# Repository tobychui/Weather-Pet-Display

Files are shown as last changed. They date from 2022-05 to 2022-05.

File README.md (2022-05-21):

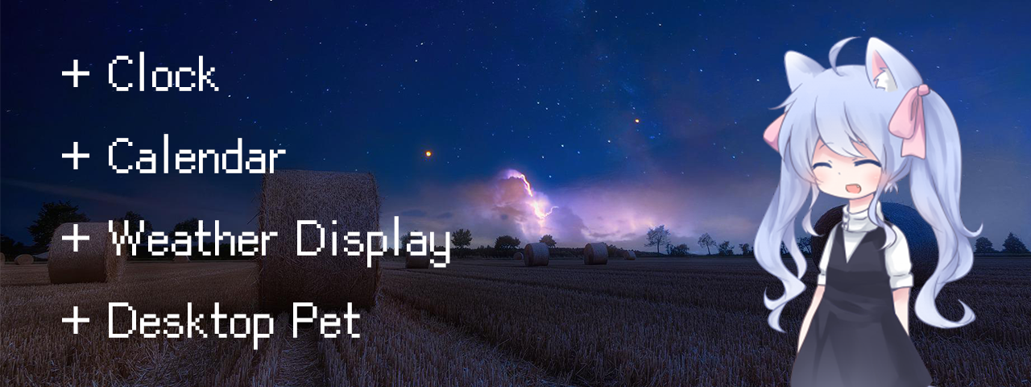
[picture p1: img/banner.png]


# Weather + Desktop Pet Display

A simple weather display with a cute interactive desktop pet  (❛◡❛✿)

## Introduction

Weather display is like one of the most done Maker project out there, involving simple parts and quite useful when put on your working desk. As a maker who is always trying to make beautiful yet technical projects, I decided to give it a try and challenge one of the most done project!

**Notes: This application provided only Tainan Weather by default (as this is where I currently live). If you need other location, please modify the code accordingly.**

## Build Instruction

### Material List

- ESP8266 (Wemos D1 Mini)
- UART HMI Display (The one used here is 5 inch touch screen model, TJC8048X550_011)
- Wires
- M3 x 10 screws x 2
- 3D printed base

### Building Instruction

1. Flash the program into the ESP8266 (See src/esp8266 folder)
2. Flash the program into the display using USART HMI Studio

3. Solder the following wires to the display 4 pin serial input

| Wemos D1 mini | UART HMI | Wire Color |
| --- | --- | --- |
| 5V | 5V | RED |
| GND | GND | BLACK |
| D1 | RX | BLUE |
| D2 | TX | YELLOW |

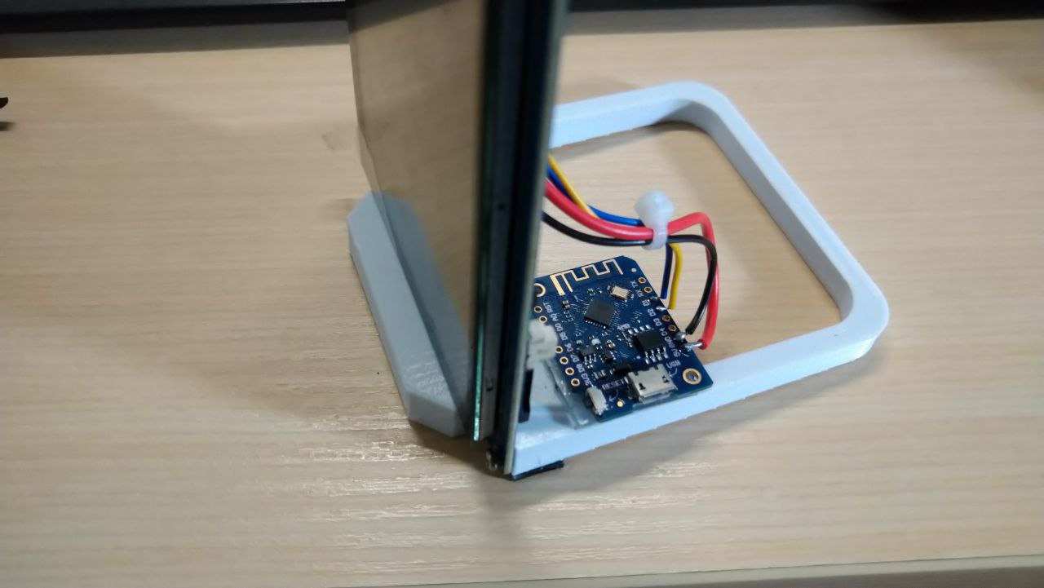
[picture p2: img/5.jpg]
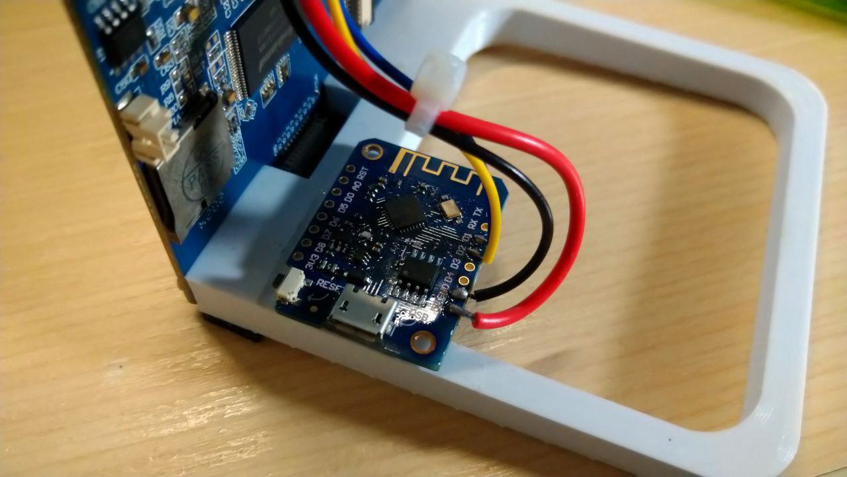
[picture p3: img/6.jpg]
|  |  |
| --- | --- |

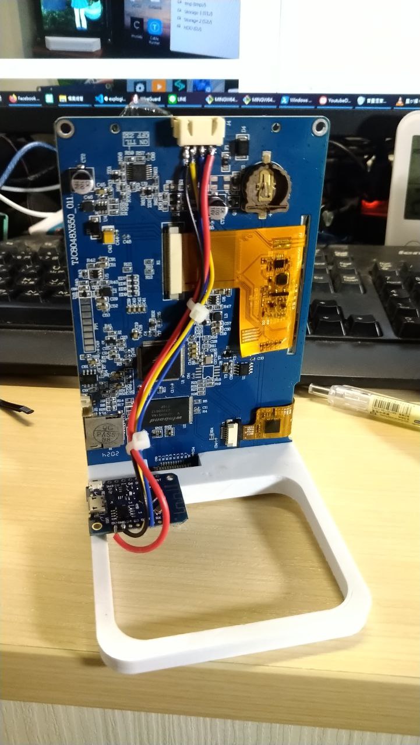
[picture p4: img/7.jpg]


4. Power it on, then it is done!

### WiFi Setup
This project uses [WiFi Manager](https://github.com/tzapu/WiFiManager). In which when ESP8266 first bootup, it will starts its own WiFi AP. You can simply connect to the WiFi AP using your phone and configure the ESP8266 to connect to your home network. Once you are done, the ESP8266 will wait for 1 secound and start grabbing weather information and date time information from the ineternet throught your home WiFi network.

## Photos

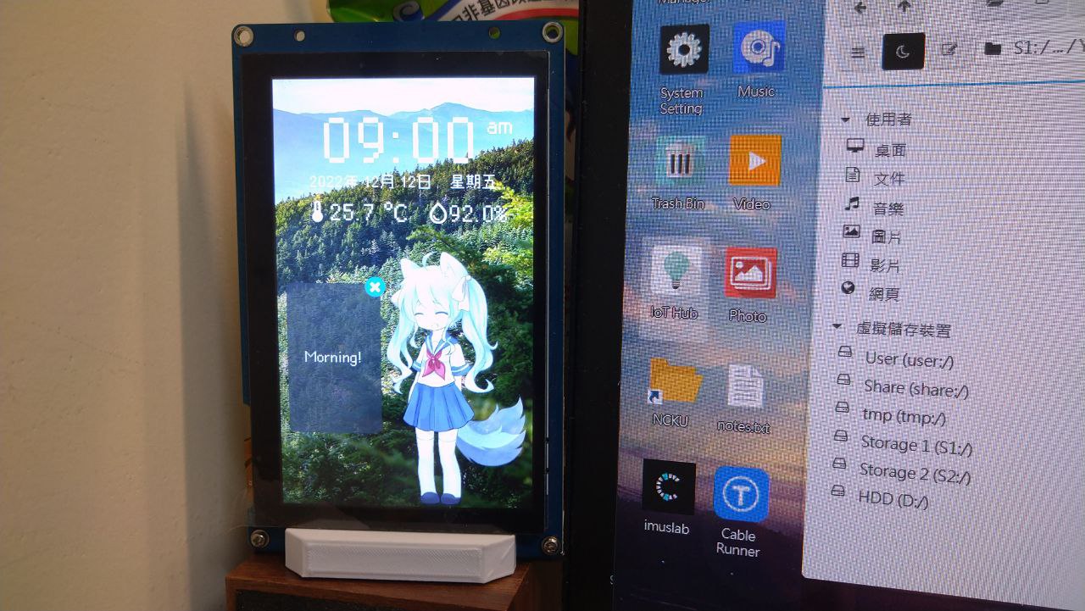
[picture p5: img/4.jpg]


Morning mode (Full brightness and in school uniform)

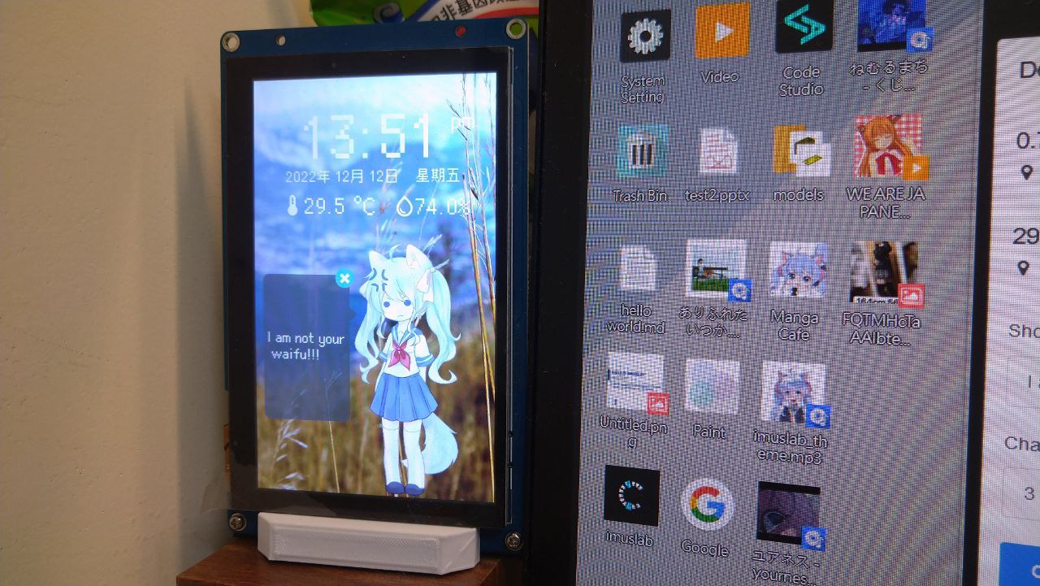
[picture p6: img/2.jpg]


Afternoon mode (Notice you can send in message and change facial expression via HTTP request)

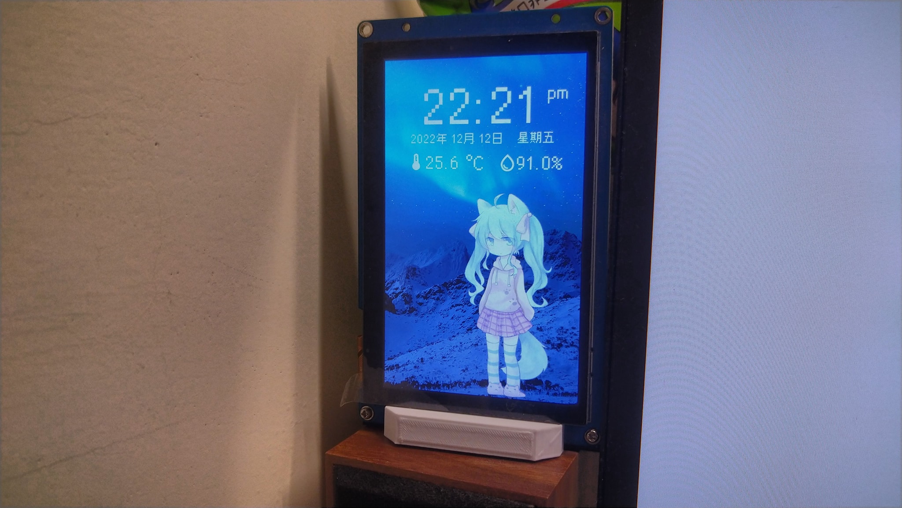
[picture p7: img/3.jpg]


Night mode, a bit more relaxing background and reduced brightness

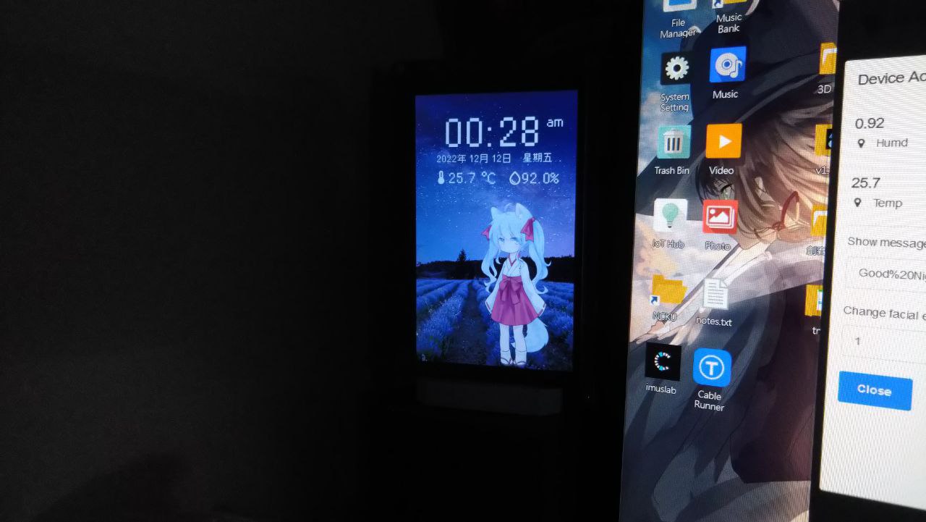
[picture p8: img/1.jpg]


Mid-night mode, set to lowest backlit LED brightness

## License

MIT

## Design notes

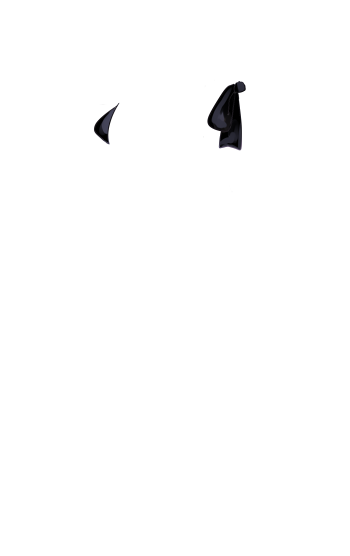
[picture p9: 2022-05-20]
src/res/ghost/surface1001.png

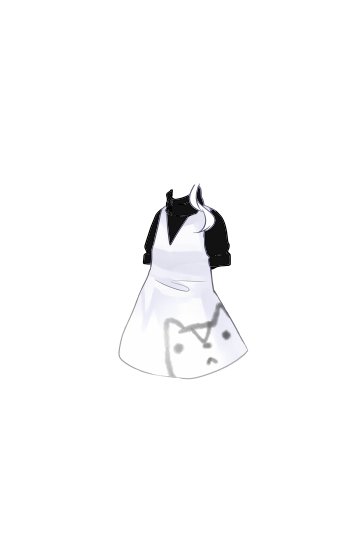
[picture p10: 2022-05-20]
src/res/ghost/surface1200.png

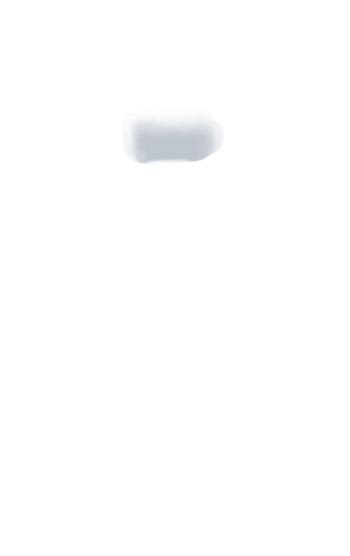
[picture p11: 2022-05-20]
src/res/ghost/surface55.png

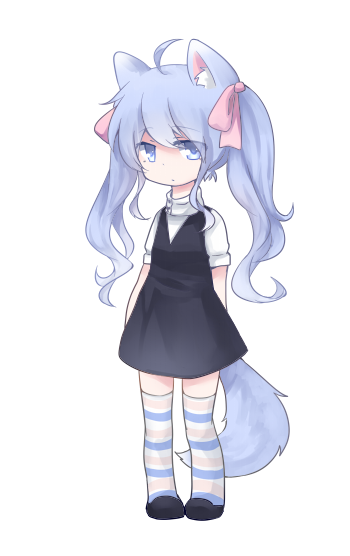
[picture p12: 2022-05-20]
src/res/ghost/surface8.png

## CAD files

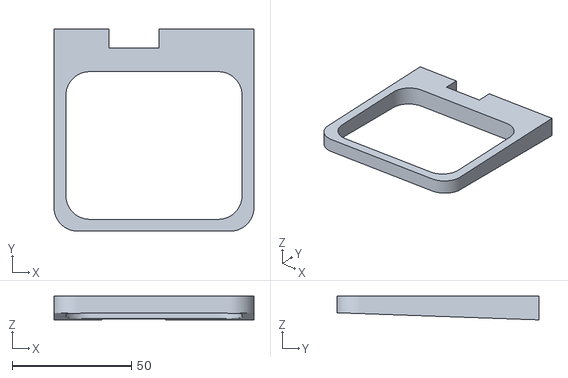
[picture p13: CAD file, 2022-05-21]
3d models/mount.stl
84.0 x 85.0 x 10.0

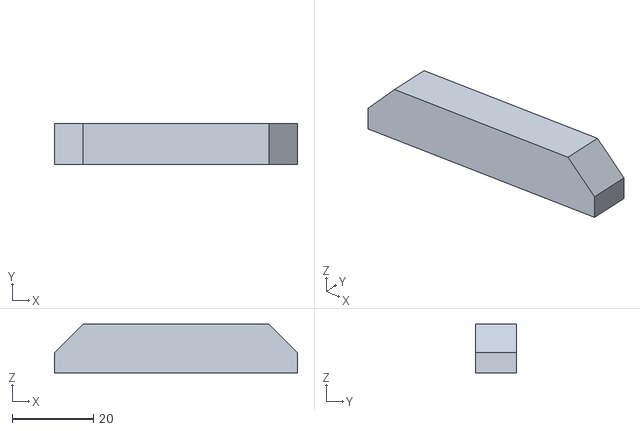
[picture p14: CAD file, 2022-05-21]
3d models/tip-over stopper.stl
60.0 x 10.0 x 12.0

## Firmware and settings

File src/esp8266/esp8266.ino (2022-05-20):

#include <ESP8266WiFi.h>
#include <NTPClient.h>
#include <WiFiUdp.h>
#include <SoftwareSerial.h>
#include <WiFiManager.h>
#include <ArduinoJson.h>

//Library required for HDSv2
#include <ESP8266mDNS.h>        // Include the mDNS library
#include <ESP8266WebServer.h>   // Include the WebServer library

//HMI Related
SoftwareSerial HMISerial(D1, D2); // RX, TX
bool debugMode = false;         //Enable debug mode

/*
 * HMI Element Definations 
 * 
 * time -> Time Display (00:00)
 * ampm -> am / pm text
 * date -> Current date, YYYY/MM/DD format 
 * dow -> Date of week, Monday to Sunday
 * 
 */
 
//WiFi Related
WiFiManager wifiManager;

//Properties of HDSv2 Devices
const String DeviceName = "ArOZ DSSP";     //The name of this IoT device
const int ListeningPort = 12110;           //The port where this IoT device listen
ESP8266WebServer server(ListeningPort);    //Create an Web Server on the listening port

//Clock Related
WiFiUDP UDPconn;
NTPClient ntpClient(UDPconn, "pool.ntp.org");
String weekDays[7]={"Sunday", "Monday", "Tuesday", "Wednesday", "Thursday", "Friday", "Saturday"};
String months[12]={"January", "February", "March", "April", "May", "June", "July", "August", "September", "October", "November", "December"};

//Weather related
//We are getting weather info from https://opendata.cwb.gov.tw/api/v1/rest/datastore/O-A0001-001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,HUMD&stationId=C0X100
const char* host = "opendata.cwb.gov.tw";
const char* stationId = "C0X100";
long cyclyCounter = 0;
DynamicJsonDocument doc(2048);
StaticJsonDocument<1024> filter;
String currentTemp = "N/A";
String currentHumd = "N/A";

//Background, messageBox & Clothing
/*
 *  Picture ID / Time
 *  30 (Early Morning): 5  - 8am
 *  31 (Morning)      : 9  - 12am
 *  32 (Afternoon)    : 13 - 15pm
 *  33 (Evening)      : 16 - 18pm
 *  34 (Night)        : 19 - 23pm
 *  35 (Late Night)   : 24 - 4am
 */

String currentBackgroundId = "0";


void setup() {
  // Start debug Serial and HMI Serial
  Serial.begin(115200);
  HMISerial.begin(9600);

  // Connect to Wi-Fi
  wifiManager.setClass("invert");
  wifiManager.autoConnect("ArOZ DSSP", "arozdssp");
  if (!debugMode){
    wifiManager.setDebugOutput(false);
  }

  //Start MDNS broadcast
  MDNS.setHostProbeResultCallback(hostProbeResult);
  if (!MDNS.begin(DeviceName) && debugMode) {
    Serial.println("Error setting up MDNS responder!");
  }

  //Advertise the port that you are using
  MDNS.addService("http", "tcp", ListeningPort);
  if (debugMode){
    Serial.println("mDNS responder started");
  }
  
  //Start WebServer
  delay(100);
  server.on("/", handle_index);
  server.on("/status", handle_status);
  server.on("/eps", handle_endpoints);
  server.on("/msg", handle_msg);
  server.on("/face", handle_face);
  
  server.begin();
  
  //Start NTP Client
  ntpClient.begin();
  ntpClient.setTimeOffset(28800);

  //Init UI Elements
  hideMessageBox();

  //Apply JSON filter
  filter["records"]["location"][0] = true;

  delay(1000);
  //Get weather information
  UpdateWeatherInfo();
}

//Dim background brightness, range 0 - 100 in string
void DimBackgroundBrightness(String brightness){
  sendCommand("dim=" + brightness);
}

//Update background by time (Current Hour)
void updateBackgroundByTime(int ch){
  String backgroundId = "35";
  if (ch >= 5 && ch <= 8){
    backgroundId = "30";
    SetClothesSet(0);
  }else if (ch >= 9 && ch <= 12){
    backgroundId = "31";
    SetClothesSet(1);
  }else if (ch >= 13 && ch <= 15){
    backgroundId = "32";
    SetClothesSet(2);
  }else if (ch >= 16 && ch <= 18){
    backgroundId = "33";
    SetClothesSet(3);
  }else if (ch >= 19 && ch <= 23){
    backgroundId = "34";
    SetClothesSet(4);
  }else if (ch >= 24 || ch <= 4){
    backgroundId = "35";
    SetClothesSet(5);
  }

  if (!currentBackgroundId.equals(backgroundId)){
       //Change of section of day, adjust brightness
       if (backgroundId.equals("30")){
          DimBackgroundBrightness("10");
       }else if (backgroundId.equals("31")){
          DimBackgroundBrightness("30");
       }else if (backgroundId.equals("32")){
          DimBackgroundBrightness("50");
       }else if (backgroundId.equals("33")){
          DimBackgroundBrightness("50");
       }else if (backgroundId.equals("34")){
          DimBackgroundBrightness("30");
       }else if (backgroundId.equals("35")){
          DimBackgroundBrightness("3");
       }
  }

  //Background need to change
  sendCommand("p3.pic=" + backgroundId);
  currentBackgroundId = backgroundId;
  
  
}

//Update the on screen display datetime
void updateTimeInfo(){
   ntpClient.update();
   time_t epochTime = ntpClient.getEpochTime();

   //Update time display
   String currentTime = timeZeroPad(ntpClient.getHours()) + ":" + timeZeroPad(ntpClient.getMinutes());
   sendCommand("time.txt=\"" + currentTime + "\"");

  //Update am/pm indicator
   String currentAfterNoon = "am";
   if (ntpClient.getHours() >=12){
      currentAfterNoon = "pm";
   }
   sendCommand("ampm.txt=\"" + currentAfterNoon + "\"");

   //Update background
   updateBackgroundByTime(ntpClient.getHours());
  
   //Updat the date display
   struct tm *ptm = gmtime ((time_t *)&epochTime); 
   String currentDate = String(ptm->tm_year+1900) + "/" + String(ptm->tm_mon+1) + "/" + String(ptm->tm_mday);
   
   //English
   //sendCommand("date.txt=\"" + currentDate + "\"");
   //Chinese
   SendDateTimeChinese(String(ptm->tm_year+1900), String(ptm->tm_mon+1), String(ptm->tm_mday));
  
  
   //Update day of week
   //English
   //String weekDay = weekDays[ntpClient.getDay()];
   //sendCommand("dow.txt=\"" + weekDay + "\"");

   //Chinese (big-5)
   SendWeekDayChinese(ntpClient.getDay());
}

void UpdateWeatherInfo(){
  WiFiClientSecure httpsClient;
  const int httpPort = 443;
  httpsClient.setInsecure();
  if (!httpsClient.connect(host, httpPort)) {
    //Fail to conenct
    if (debugMode){
      Serial.println("connection failed");
    }
    return;
  }

    //Create URI request
    String url = "/api/v1/rest/datastore/O-A0001-001?Authorization=rdec-key-123-45678-011121314&limit=40&format=JSON&elementName=TEMP,HUMD&stationId=";
    url += stationId;
    httpsClient.print(String("GET ") + url + " HTTP/1.1\r\n" +
               "Host: " + host + "\r\n" + 
               "Connection: close\r\n\r\n");

    while (httpsClient.connected()) {
      String line = httpsClient.readStringUntil('\n');
      if (line == "\r") {
        break;
      }
    }

    String line;
    String reply = "";
    while(httpsClient.available()){        
      line = httpsClient.readStringUntil('\n');  //Read Line by Line
      reply += line;
    }

    //Trim the first unwannted byte and the last
    int startTrimPos = reply.indexOf("{");
    int lastTrimPos = reply.lastIndexOf("}");
    reply = reply.substring(startTrimPos, lastTrimPos);

    //Serial.println(reply);
    deserializeJson(doc, reply);
    String temp = doc["records"]["location"][0]["weatherElement"][0]["elementValue"];
    String humd = doc["records"]["location"][0]["weatherElement"][1]["elementValue"];
    double humdPercentage = humd.toDouble() * 100;

    //Update the on-screen weather information
    sendCommand("temp.txt=\"" + temp + "\"");
    printFloatCommand("humi.txt=", humdPercentage, "");

    //Update global cache variable, force copying
    currentTemp = "" + temp;
    currentHumd = "" + humd;

}

void loop() {
  //Update Clock Display
  updateTimeInfo();
  
  //Update Messagebox display status
  updateMessageboxStatus();

  //Handle web requests
  server.handleClient();
  MDNS.update();

  //Update weather information
  if (cyclyCounter%1800 == 0){
    //Update weather info every 30 min +- 10min
    UpdateWeatherInfo();
    cyclyCounter = 0; //prevent overflow
  }

  cyclyCounter++;
  delay(100);
}

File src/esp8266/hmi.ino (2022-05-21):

/*
 * 
 *  HMI Communication Script
 *  
 *  This script helps you to communicate with the HMI display
 *  from 
 */
// Send command to the UART HMI
// Example usage: sendCommand("t3.txt=\"OUTPUT\"");

bool nextReadIsPageNumber = false; //Next byte is page number
byte incomingByte = 0;             //Incoming byte buffer

void sendCommand(String cmd){
  if (debugMode){
    //Mirror output to serial
    Serial.print(cmd);
    Serial.write(0XFF);        
    Serial.write(0XFF);
    Serial.write(0XFF);
  }
  HMISerial.print(cmd); 
  HMISerial.write(0XFF);
  HMISerial.write(0XFF);
  HMISerial.write(0XFF);
  delay(100);
}

//Send Float to the display, support -99 to +99 range, automatic turncat into 4 digit with unit
//Example usage: printFloatCommand("t6.txt=", 16.8, "V");
void printFloatCommand(String cmd, float value, String unit){
  if (debugMode){
    //Mirror output to serial
    Serial.print(cmd + "\"");
    if (value <= -10){
      Serial.print(value, 1);
    }else if (value < 0){
      Serial.print(value, 2);
    }else if (value < 10){
       Serial.print(value, 2);
    }else{
      Serial.print(value, 1);
    }
    Serial.print(unit + "\"");
    Serial.write(0XFF);        
    Serial.write(0XFF);
    Serial.write(0XFF);
  }
  HMISerial.print(cmd + "\"");
  if (value <= -10){
    HMISerial.print(value, 1);
  }else if (value < 0){
    HMISerial.print(value, 2);
  }else if (value < 10){
    HMISerial.print(value, 2);
  }else{
    HMISerial.print(value, 1);
  }
  HMISerial.print(unit + "\"");
  HMISerial.write(0XFF);
  HMISerial.write(0XFF);
  HMISerial.write(0XFF);
  delay(100);
}

//Facial Expression
void changeFacialExpression(int expr){
   if (expr==0){
    //default face
    sendCommand("gm0.vid=1");
    sendCommand("expr.pic=26");
    sendCommand("expr.aph=127");
    sendCommand("expr2.aph=0");
   }else if (expr == 1){
    //happy face
    sendCommand("gm0.vid=0");
    sendCommand("expr.pic=17");
    sendCommand("expr.aph=127");
    sendCommand("expr2.aph=0");
   }else if (expr == 2){
    //shy face
    sendCommand("gm0.vid=1");
    sendCommand("expr.pic=20");
    sendCommand("expr.aph=127");
    sendCommand("expr2.pic=26");
    sendCommand("expr2.aph=127");
   }else if (expr == 3){
    //angry face
    sendCommand("gm0.vid=1");
    sendCommand("expr.pic=13");
    sendCommand("expr.aph=127");
    sendCommand("expr2.pic=22");
    sendCommand("expr2.aph=127");
   }else if (expr == 4){
    //shock face
    sendCommand("gm0.vid=1");
    sendCommand("expr.pic=19");
    sendCommand("expr.aph=127");
    sendCommand("expr2.pic=23");
    sendCommand("expr2.aph=127");
   }else if (expr == 5){
    //look away face
    sendCommand("gm0.vid=1");
    sendCommand("expr.pic=12");
    sendCommand("expr.aph=127");
    sendCommand("expr2.pic=26");
    sendCommand("expr2.aph=127");
   }else if (expr == 6){
    //look down face
    sendCommand("gm0.vid=1");
    sendCommand("expr.pic=15");
    sendCommand("expr.aph=127");
    sendCommand("expr2.aph=0");
   }else{
    //default
    sendCommand("gm0.vid=1");
    sendCommand("expr.pic=26");
    sendCommand("expr.aph=127");
    sendCommand("expr2.aph=0");
   }
}

//Show the messagebox
void showMessageBoxWithText(String stringToSend){
  sendCommand("t1.txt=\"" + stringToSend + "\"");
  sendCommand("p4.aph=100");
  sendCommand("t1.aph=127");
  sendCommand("b8.aph=127");
}

void hideMessageBox(){
  sendCommand("p4.aph=0");
  sendCommand("t1.aph=0");
  sendCommand("b8.aph=0");
}

//Get the current page number on HMI
int getPageNumber(){
  //Request the UART HMI to return its current page number
  sendCommand("sendme");

  //Try to parse and catch the return value
  bool nextReadIsPageNumber = false;
  if (debugMode){
    //Debug mode
    while (Serial.available() > 0) {
      // read the incoming byte:
      incomingByte = Serial.read();
      if (nextReadIsPageNumber){
        //This read is the page number
        nextReadIsPageNumber = false;
        return incomingByte;
      }

      if (incomingByte == 0x66){
        //This is the start of a page response
        nextReadIsPageNumber = true;
      }
    }
  }else{
    while (HMISerial.available() > 0) {
      // read the incoming byte:
      incomingByte = HMISerial.read();
      if (nextReadIsPageNumber){
        //This read is the page number
        nextReadIsPageNumber = false;
        return incomingByte;
      }

      if (incomingByte == 0x66){
        //This is the start of a page response
        nextReadIsPageNumber = true;
      }
    }
  }

  return -1;
}

void SendDateTimeChinese(String year, String month, String day){
  if (debugMode){
    Serial.print("date.txt=\"");
    Serial.print(year);
    Serial.write(0xA6); //年
    Serial.write(0x7E);
    
    Serial.print(month);
    Serial.write(0xA4); //月
    Serial.write(0xEB);
    
    Serial.print(day);
    Serial.write(0xA4); //日
    Serial.write(0xE9);
  
    Serial.print("\"");
    Serial.write(0XFF);
    Serial.write(0XFF);
    Serial.write(0XFF);
  }
  HMISerial.print("date.txt=\"");
  HMISerial.print(year);
  HMISerial.write(0xA6); //年
  HMISerial.write(0x7E);
  
  HMISerial.print(month);
  HMISerial.write(0xA4); //月
  HMISerial.write(0xEB);
  
  HMISerial.print(day);
  HMISerial.write(0xA4); //日
  HMISerial.write(0xE9);

  HMISerial.print("\"");
  HMISerial.write(0XFF);
  HMISerial.write(0XFF);
  HMISerial.write(0XFF);
  delay(100);
}
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

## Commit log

2022-05-21 Added mount 3D model file and gcode files
    [mount.stl, tip-over stopper.stl]
2022-05-21 Fixed minor bug on date display
    [esp8266.ino, hmi.ino]
